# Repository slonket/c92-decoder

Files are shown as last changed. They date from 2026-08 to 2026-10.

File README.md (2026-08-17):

# c92-decoder

### An MM1/MM2/Lenz decoder for classic Märklin locomotives and the pre-mfx digital systems.

The c92 decoder was spawned out of a passion for the classic (pre-mfx) Märklin digital systems. The controllers of this era operated with three different protocols:
- MM1 (6020, 6021, 6022, 6023)
- MM2 (6021)
- Lenz (6027, 6029)

However, no single decoder from this era can operate on all three protocols, nor with all of their capabilities. Furthermore, there is a matrix of incompatibility between different controllers and combinations of decoders using MM1 and MM2. The c92 decoder is a superset of all decoder capabilities and their respective protocols; a universal classic decoder.

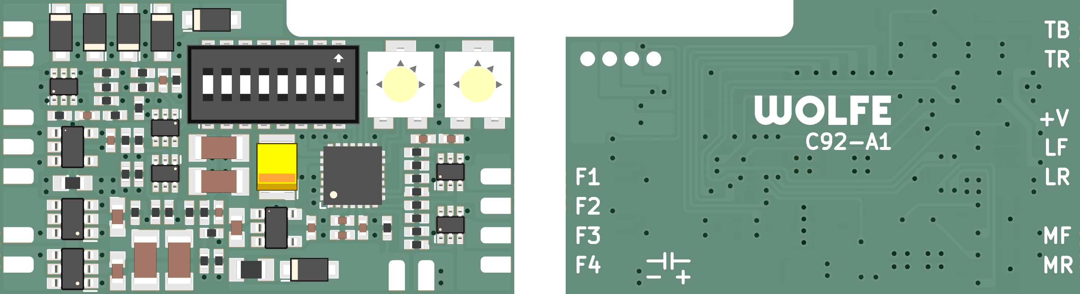
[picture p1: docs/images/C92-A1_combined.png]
c92 decoder back view.


### Cloning

This project uses [`slonket-footprints`](https://github.com/slonket/slonket-footprints) as a submodule for all PCB designs. All KiCAD projects within this repository are configured to use the submodule libraries with local paths. Run the following to clone the repository with its submodule:
```
git clone --recurse-submodules https://github.com/slonket/c92-decoder.git
```

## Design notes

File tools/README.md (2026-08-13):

# c92-decoder - tools

### discrete_hbridge

A development board for the discrete H-bridge design used in the c92 decoder. The H-bridge is unique in being able to operate with low-side FETs always on, while PWM is applied only to the top FETs. This mode is necessary for BEMF measurement referenced to decoder ground.

### hubert_mounts

Mounting hardware for a breadboard to be fastened atop Hubert.

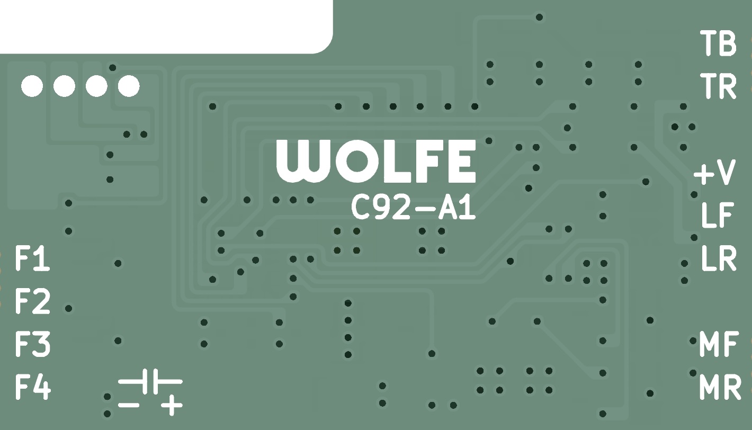
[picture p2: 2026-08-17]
docs/images/C92-A1_back.jpg

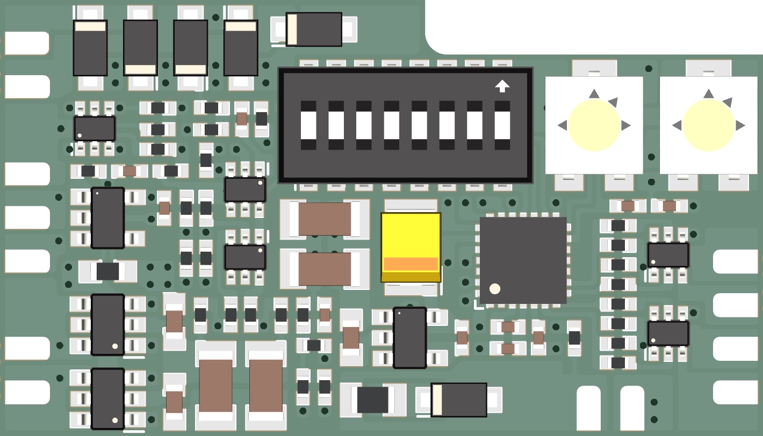
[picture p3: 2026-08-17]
docs/images/C92-A1_front.jpg

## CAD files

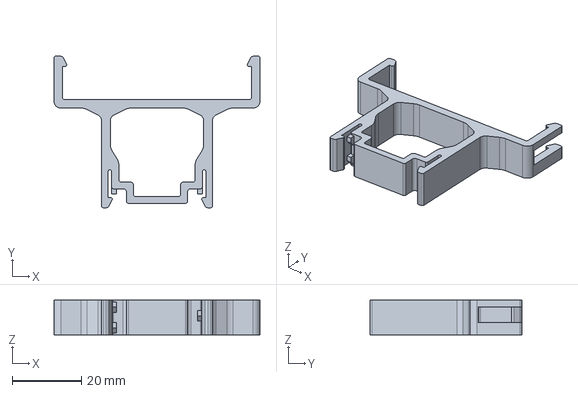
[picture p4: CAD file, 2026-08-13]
tools/hubert_mounts/hubert_mount_B.FCStd
59.5 x 43.8 x 10.0 mm

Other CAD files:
mechanical/C92_bracket.FCStd
tools/hubert_mounts/hubert_mount_A.FCStd

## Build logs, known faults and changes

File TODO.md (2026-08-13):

# c92-decoder

### TODO

- [ ] Write a comprehensive README.md
- [ ] Implement F1-F4 GPIO (held by decoder_state?).
    - Framework DONE - need F3/F4 GPIO setup.
- [ ] Make acceleration potentiometer non-linear and with better range in motor control.
- [ ] Add emergency stop and decoder disable for motor current limit trip.
- [ ] Add analog (DC) operation.
- [ ] Add marklin braking section detection.
- [ ] Store absolute direction in flash between power cycles for MM1.
    - [ ] Store complete state with F1-F4. Use brownout detection?
- [ ] Check MM 81-255 work on other controllers like MS2.
    - [ ] Check the 83-191 address swap on IB-Basic isn't just a bug.
    - [ ] Check all addresses work.
- [x] Connect F4 state to ramp bypass in motor control.
- [x] Add motorola old functions F1-F4.
- [x] Extend MM to use 255 addresses.

### Issues

- [x] The headlight F0 (decoder state) and motor drive direction can go out of sync on motorola old. this is likely due to the use of "change direction" rather than "absolute direction". It is hard to replicate this bug but the change likely requires update_reverse() to provide an absolute direction, and to not use "reverse" on motor_control. This keeps motor_state and motor_control in sync and lets motor_state exclusively handle detection of direction changes.
    - FIXED - Removed reverse in motor control. It is now absolute from decoder state.
- [x] Loco moves briefly in new direction after reverse on MM1.'
    - FIXED - Reversing would only change direction, but not update speed. Fixed by setting motor speed to 0 after update_reverse() for decoder state.

### Revisit

- [ ] Feedback control and PI control system tuning.
- [ ] Speed range minimum value from potentiometer.
    - [ ] Minimum (crawl) speed tuning.
- [ ] Accelation range from potentiometer.
- [ ] Lenz/MM pulse timing tolerances (notably MM between controllers).
- [ ] Initial GPIO states for functions and motor outputs.

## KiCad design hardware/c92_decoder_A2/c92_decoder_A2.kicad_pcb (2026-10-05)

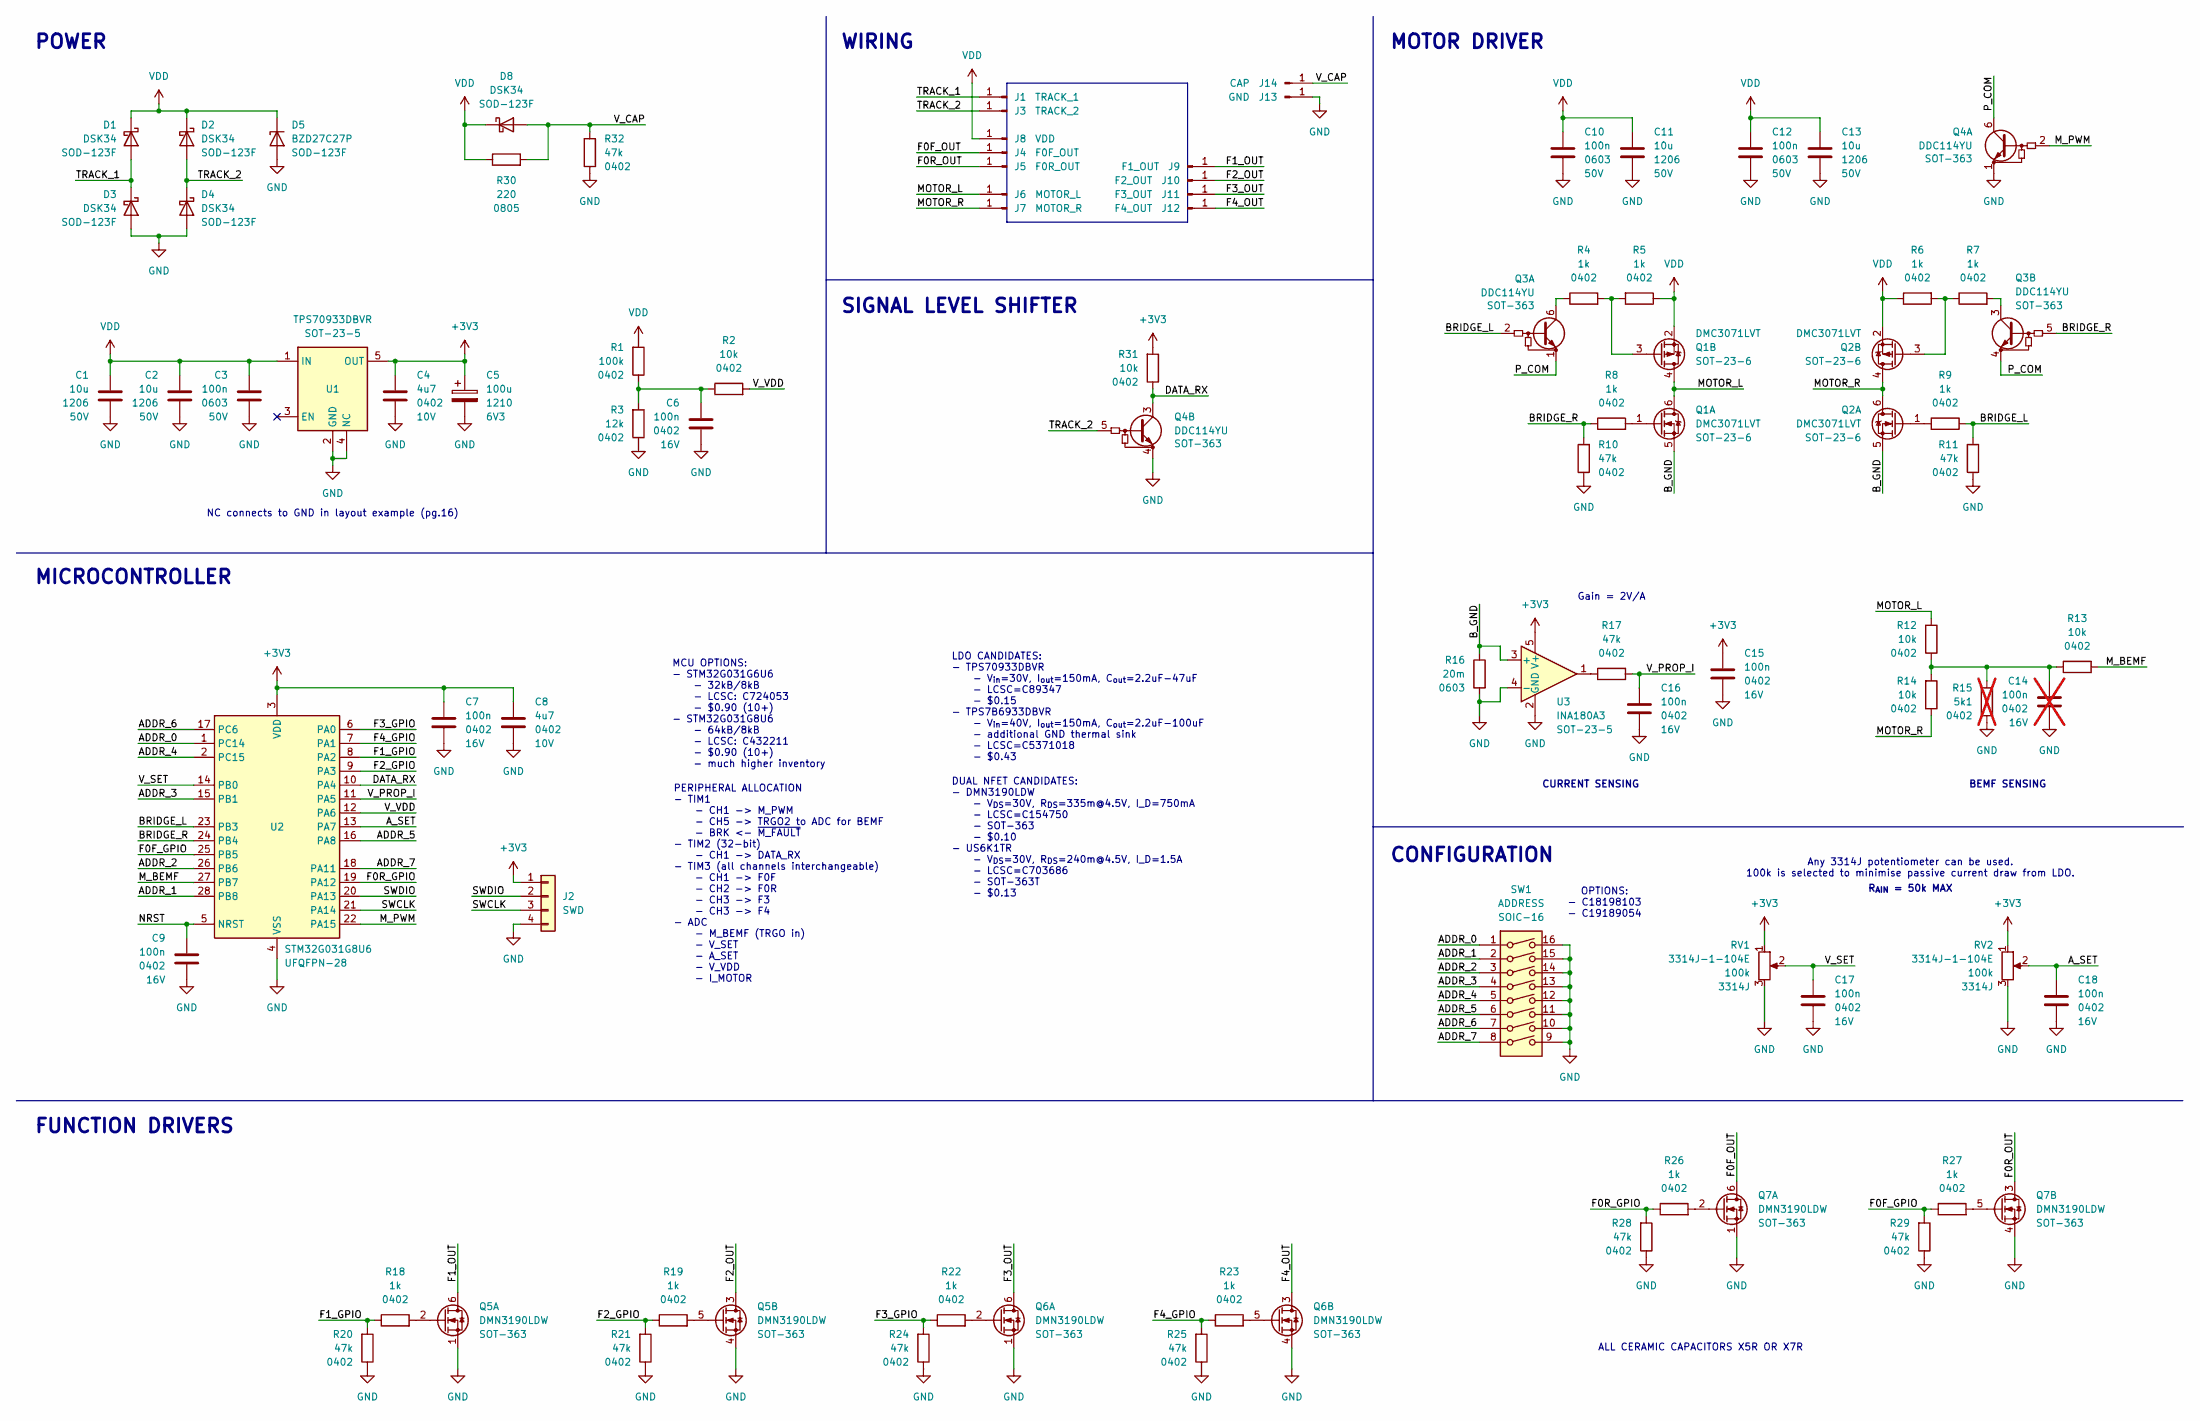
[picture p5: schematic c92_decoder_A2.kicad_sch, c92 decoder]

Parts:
C1, C2, C11, C13: 10u; C_1206; Voltage 50V; LCSC C13585
C3, C10, C12: 100n; C_0603; Voltage 50V; LCSC C14663
C4, C8: 4u7; C_0402; Voltage 10V; LCSC C23733
C5: 100u; CP_1210_CASE_B; Voltage 6V3; LCSC C16133
C6, C7, C9, C15, C16, C17, C18: 100n; C_0402; Voltage 16V; LCSC C1525
C14: 100n; C_0402; Voltage 16V; LCSC C1525; not fitted
D1, D2, D3, D4, D8: DSK34; D_SOD-123F; LCSC C7502709
D5: BZD27C27P; D_SOD-123F; LCSC C5455754
J1: TRACK_1; J_Pad_1mm_2mm
J2: SWD; J_Pad_4_1.5mm
J3: TRACK_2; J_Pad_1mm_2mm
J4: F0F_OUT; J_Pad_1mm_2mm
J5: F0R_OUT; J_Pad_1mm_2mm
J6: MOTOR_L; J_Pad_1mm_2mm
J7: MOTOR_R; J_Pad_1mm_2mm
J8: VDD; J_Pad_1mm_2mm
J9: F1_OUT; J_Pad_1mm_2mm
J10: F2_OUT; J_Pad_1mm_2mm
J11: F3_OUT; J_Pad_1mm_2mm
J12: F4_OUT; J_Pad_1mm_2mm
J13: GND; J_Pad_1mm_2mm
J14: CAP; J_Pad_1mm_2mm
Q1, Q2: DMC3071LVT; U_SOT-23-6; LCSC C17543297
Q3, Q4: DDC114YU; U_SOT-363; LCSC C151389
Q5, Q6, Q7: DMN3190LDW; U_SOT-363; LCSC C154750
R1: 100k; R_0402; LCSC C25741
R2, R12, R13, R14, R31: 10k; R_0402; LCSC C25744
R3: 12k; R_0402; LCSC C25752
R4, R5, R6, R7, R8, R9, R18, R19, R22, R23, R26, R27: 1k; R_0402; LCSC C11702
R10, R11, R17, R20, R21, R24, R25, R28, R29, R32: 47k; R_0402; LCSC C25792
R15: 5k1; R_0402; LCSC C25905; not fitted
R16: 20m; R_0603; LCSC C156372
R30: 220; R_0805; LCSC C17557
RV1, RV2: 3314J-1-104E; RV_BOURNS_3314J; LCSC C51284
SW1: ADDRESS; SW_DIP_8_P1.27; LCSC C18198103
U1: TPS70933DBVR; U_SOT-23-5; LCSC C89347
U2: STM32G031G8U6; U_STM_UFQFPN-28_4x4_P0.5; LCSC C432211
U3: INA180A3; U_SOT-23-5; LCSC C122882

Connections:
+3V3: C4.1, C5.1, C7.1, C8.1, C15.1, J2.1, R31.2, RV1.1, RV2.1, U1.5 (OUT), U2.3 (VDD), U3.5 (V+)
/ADDR_0: SW1.1, U2.1 (PC14)
/ADDR_1: SW1.2, U2.28 (PB8)
/ADDR_2: SW1.3, U2.26 (PB6)
/ADDR_3: SW1.4, U2.15 (PB1)
/ADDR_4: SW1.5, U2.2 (PC15)
/ADDR_5: SW1.6, U2.16 (PA8)
/ADDR_6: SW1.7, U2.17 (PC6)
/ADDR_7: SW1.8, U2.18 (PA11)
/A_SET: C18.1, RV2.2, U2.13 (PA7)
/BRIDGE_L: Q3.2 (B1), R9.1, R11.2, U2.23 (PB3)
/BRIDGE_R: Q3.5 (B2), R8.1, R10.2, U2.24 (PB4)
/B_GND: Q1.5 (S), Q2.5 (S), R16.1, U3.3 (+)
/DATA_RX: Q4.3 (C2), R31.1, U2.10 (PA4)
/F0F_GPIO: R27.1, R29.2, U2.25 (PB5)
/F0F_OUT: J4.1 (Pin_1_1), Q7.6 (D)
/F0R_GPIO: R26.1, R28.2, U2.19 (PA12)
/F0R_OUT: J5.1 (Pin_1_1), Q7.3 (D)
/F1_GPIO: R18.1, R20.2, U2.8 (PA2)
/F1_OUT: J9.1 (Pin_1_1), Q5.6 (D)
/F2_GPIO: R19.1, R21.2, U2.9 (PA3)
/F2_OUT: J10.1 (Pin_1_1), Q5.3 (D)
/F3_GPIO: R22.1, R24.2, U2.6 (PA0)
/F3_OUT: J11.1 (Pin_1_1), Q6.6 (D)
/F4_GPIO: R23.1, R25.2, U2.7 (PA1)
/F4_OUT: J12.1 (Pin_1_1), Q6.3 (D)
/MOTOR_L: J6.1 (Pin_1_1), Q1.4 (D), Q1.6 (D), R12.2
/MOTOR_R: J7.1 (Pin_1_1), Q2.4 (D), Q2.6 (D), R14.1
/M_BEMF: R13.2, U2.27 (PB7)
/M_PWM: Q4.2 (B1), U2.22 (PA15)
/NRST: C9.1, U2.5 (NRST)
/P_COM: Q3.1 (E1), Q3.4 (E2), Q4.6 (C1)
/SWCLK: J2.3, U2.21 (PA14)
/SWDIO: J2.2, U2.20 (PA13)
/TRACK_1: D1.2 (A), D3.1 (K), J1.1 (Pin_1_1)
/TRACK_2: D2.2 (A), D4.1 (K), J3.1 (Pin_1_1), Q4.5 (B2)
/V_CAP: D8.2 (A), J14.1 (Pin_1_1), R30.2, R32.2
/V_PROP_I: C16.1, R17.2, U2.11 (PA5)
/V_SET: C17.1, RV1.2, U2.14 (PB0)
/V_VDD: R2.2, U2.12 (PA6)
GND: C1.2, C2.2, C3.2, C4.2, C5.2, C6.2, C7.2, C8.2, C9.2, C10.2, C11.2, C12.2, C13.2, C14.2, C15.2, C16.2, C17.2, C18.2, D3.2 (A), D4.2 (A), D5.2 (A), J2.4, J13.1 (Pin_1_1), Q4.1 (E1), Q4.4 (E2), Q5.1 (S), Q5.4 (S), Q6.1 (S), Q6.4 (S), Q7.1 (S), Q7.4 (S), R3.1, R10.1, R11.1, R15.1, R16.2, R20.1, R21.1, R24.1, R25.1, R28.1, R29.1, R32.1, RV1.3, RV2.3, SW1.9, SW1.10, SW1.11, SW1.12, SW1.13, SW1.14, SW1.15, SW1.16, U1.2 (GND), U1.4 (NC), U2.4 (VSS), U3.2 (GND), U3.4 (-)
unnamed: C6.1, R1.1, R2.1, R3.2
unnamed: C14.1, R12.1, R13.1, R14.2, R15.2
unnamed: Q1.1 (G), R8.2
unnamed: Q1.3 (G), R4.2, R5.2
unnamed: Q2.1 (G), R9.2
unnamed: Q2.3 (G), R6.2, R7.1
unnamed: Q3.6 (C1), R4.1
unnamed: Q3.3 (C2), R7.2
unnamed: Q5.2 (G), R18.2
unnamed: Q5.5 (G), R19.2
unnamed: Q6.2 (G), R22.2
unnamed: Q6.5 (G), R23.2
unnamed: Q7.2 (G), R26.2
unnamed: Q7.5 (G), R27.2
unnamed: R17.1, U3.1
VDD: C1.1, C2.1, C3.1, C10.1, C11.1, C12.1, C13.1, D1.1 (K), D2.1 (K), D5.1 (K), D8.1 (K), J8.1 (Pin_1_1), Q1.2 (S), Q2.2 (S), R1.2, R5.1, R6.1, R30.1, U1.1 (IN)

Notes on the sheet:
PERIPHERAL ALLOCATION - TIM1 - CH1 -> M_PWM - CH5 -> TRGO2 to ADC for BEMF - BRK <- ~{M_FAULT} - TIM2 (32-bit) - CH1 -> DATA_RX - TIM3 (all channels interchangeable) - CH1 -> F0F - CH2 -> F0R - CH3 -> F3 - CH3 -> F4 - ADC - M_BEMF (TRGO in) - V_SET - A_SET - V_VDD - I_MOTOR
Any 3314J potentiometer can be used. 100k is selected to minimise passive current draw from LDO.
MOTOR DRIVER
ALL CERAMIC CAPACITORS X5R OR X7R
SIGNAL LEVEL SHIFTER
POWER
Gain = 2V/A
DUAL NFET CANDIDATES: - DMN3190LDW - V_{DS}=30V, R_{DS}=335m@4.5V, I_D=750mA - LCSC=C154750 - SOT-363 - $0.10 - US6K1TR - V_{DS}=30V, R_{DS}=240m@4.5V, I_D=1.5A - LCSC=C703686 - SOT-363T - $0.13
OPTIONS: - C18198103 - C19189054
CURRENT SENSING
NC connects to GND in layout example (pg.16)
BEMF SENSING
MCU OPTIONS: - STM32G031G6U6 - 32kB/8kB - LCSC: C724053 - $0.90 (10+) - STM32G031G8U6 - 64kB/8kB - LCSC: C432211 - $0.90 (10+) - much higher inventory
WIRING
CONFIGURATION
FUNCTION DRIVERS
MICROCONTROLLER
LDO CANDIDATES: - TPS70933DBVR - V_{in}=30V, I_{out}=150mA, C_{out}=2.2uF-47uF - LCSC=C89347 - $0.15 - TPS7B6933DBVR - V_{in}=40V, I_{out}=150mA, C_{out}=2.2uF-100uF - additional GND thermal sink - LCSC=C5371018 - $0.43
R_{AIN} = 50k MAX

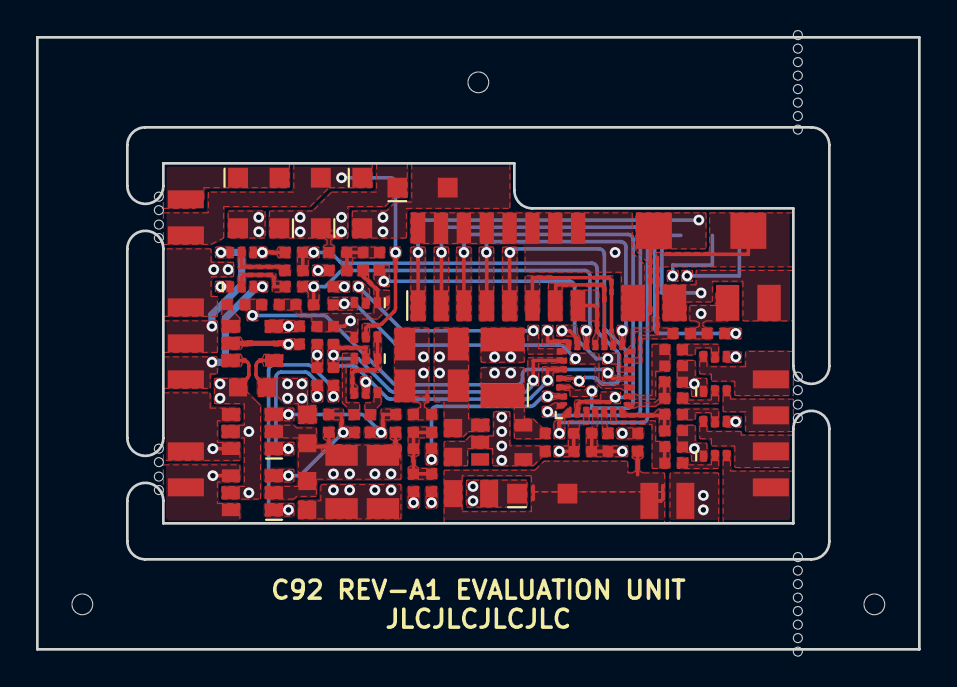
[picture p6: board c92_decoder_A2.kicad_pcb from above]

Board: 4 copper layers, 49.0 x 34.0 mm, 83 parts (1 on the bottom side), 57 nets.

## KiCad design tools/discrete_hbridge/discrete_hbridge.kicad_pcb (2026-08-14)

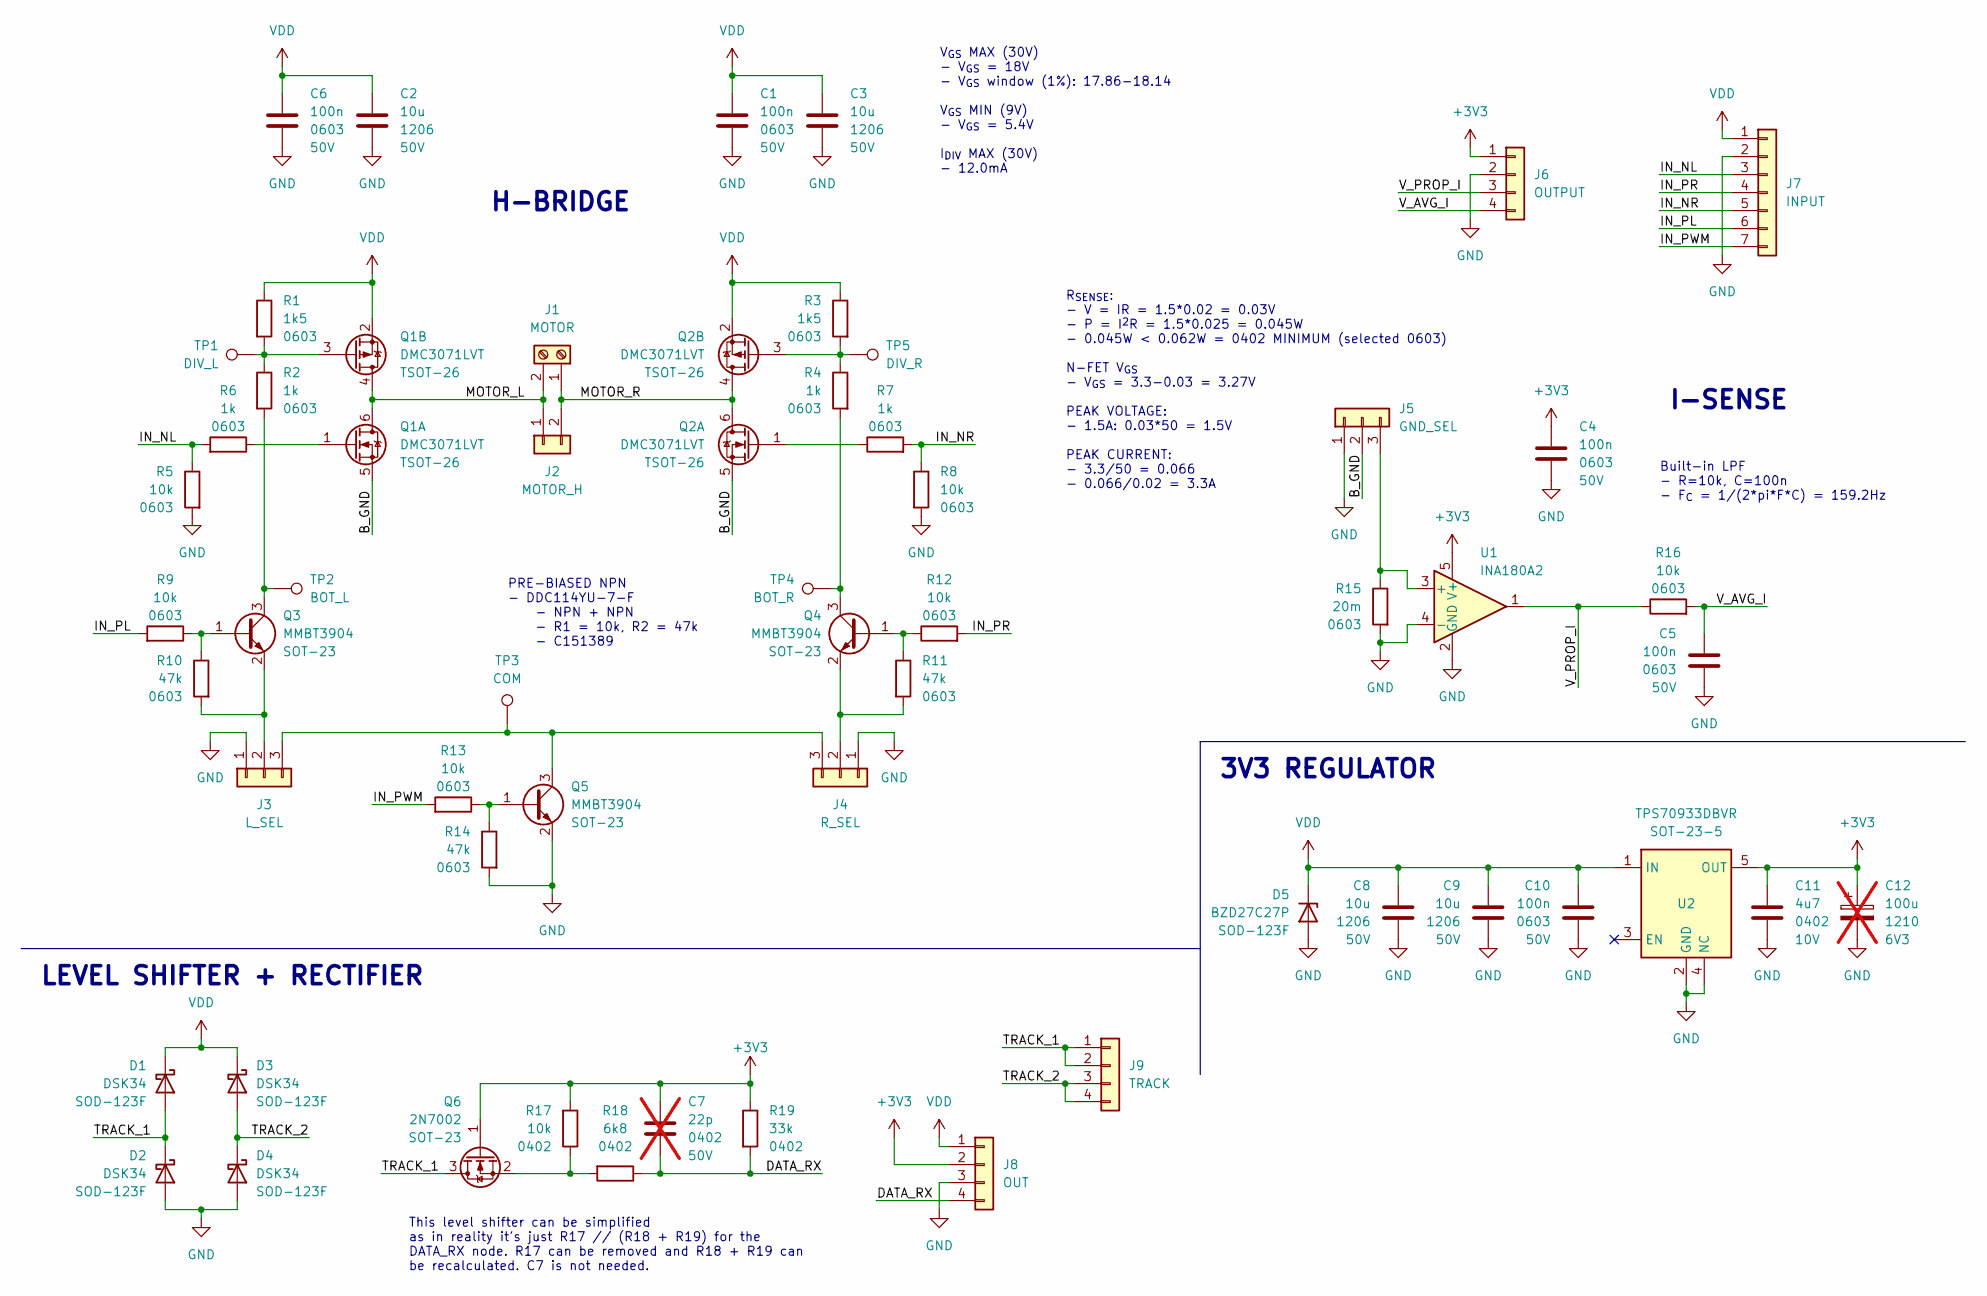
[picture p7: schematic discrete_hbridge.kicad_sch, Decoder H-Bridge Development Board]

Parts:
C1, C4, C5, C6: 100n; C_0603_1608Metric; Voltage 50V; LCSC C14663
C2, C3: 10u; C_1206_3216Metric; Voltage 50V; LCSC C13585
C7: 22p; C_0402; Voltage 50V; LCSC C1653; not fitted
C8, C9: 10u; C_1206; Voltage 50V; LCSC C13585
C10: 100n; C_0603; Voltage 50V; LCSC C14663
C11: 4u7; C_0402; Voltage 10V; LCSC C23733
C12: 100u; CP_1210_CASE_B; Voltage 6V3; LCSC C16133; not fitted
D1, D2, D3, D4: DSK34; D_SOD-123F; LCSC C7502709
D5: BZD27C27P; D_SOD-123F; LCSC C5455754
J1: MOTOR; TerminalBlock_MaiXu_MX126-5.0-02P_1x02_P5.00mm
J2: MOTOR_H; PinHeader_1x02_P2.54mm_Vertical
J3: L_SEL; PinHeader_1x03_P2.54mm_Vertical
J4: R_SEL; PinHeader_1x03_P2.54mm_Vertical
J5: GND_SEL; PinHeader_1x03_P2.54mm_Vertical
J6: OUTPUT; PinHeader_1x04_P2.54mm_Vertical
J7: INPUT; PinHeader_1x07_P2.54mm_Vertical
J8: OUT; PinHeader_1x04_P2.54mm_Vertical
J9: TRACK; PinHeader_1x04_P2.54mm_Vertical
Q1, Q2: DMC3071LVT; TSOT-23-6; LCSC C17543297
Q3, Q4, Q5: MMBT3904; SOT-23; LCSC C7420353
Q6: 2N7002; U_SOT-23; LCSC C8545
R1, R3: 1k5; R_0603_1608Metric; LCSC C22843
R2, R4, R6, R7: 1k; R_0603_1608Metric; LCSC C21190
R5, R8, R9, R12, R13, R16: 10k; R_0603_1608Metric; LCSC C25804
R10, R11, R14: 47k; R_0603_1608Metric; LCSC C25819
R15: 20m; R_0603_1608Metric; LCSC C156372
R17: 10k; R_0402; LCSC C25744
R18: 6k8; R_0402; LCSC C25917
R19: 33k; R_0402; LCSC C25779
TP1: DIV_L; TP_Loop
TP2: BOT_L; TP_Loop
TP3: COM; TP_Loop
TP4: BOT_R; TP_Loop
TP5: DIV_R; TP_Loop
U1: INA180A2; SOT-23-5; LCSC C192764
U2: TPS70933DBVR; U_SOT-23-5; LCSC C89347

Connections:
+3V3: C4.1, C7.1, C11.1, C12.1, J6.1, J8.2, Q6.1 (G), R17.2, R19.1, U1.5 (V+), U2.5 (OUT)
/B_GND: J5.2, Q1.5 (S), Q2.5 (S)
/DATA_RX: C7.2, J8.4, R18.1, R19.2
/IN_NL: J7.3, R5.1, R6.2
/IN_NR: J7.5, R7.2, R8.1
/IN_PL: J7.6, R9.2
/IN_PR: J7.4, R12.2
/IN_PWM: J7.7, R13.2
/MOTOR_L: J1.2, J2.1, Q1.4 (D), Q1.6 (D)
/MOTOR_R: J1.1, J2.2, Q2.4 (D), Q2.6 (D)
/TRACK_1: D1.2 (A), D2.1 (K), J9.1, J9.2, Q6.3 (D)
/TRACK_2: D3.2 (A), D4.1 (K), J9.3, J9.4
/V_AVG_I: C5.1, J6.4, R16.2
/V_PROP_I: J6.3, R16.1, U1.1
GND: C1.2, C2.2, C3.2, C4.2, C5.2, C6.2, C8.2, C9.2, C10.2, C11.2, C12.2, D2.2 (A), D4.2 (A), D5.2 (A), J3.1, J4.1, J5.1, J6.2, J7.2, J8.3, Q5.2 (E), R5.2, R8.2, R14.2, R15.2, U1.2 (GND), U1.4 (-), U2.2 (GND), U2.4 (NC)
unnamed: J3.2, Q3.2 (E), R10.2
unnamed: J3.3, J4.3, Q5.3 (C), TP3.1 (1_1)
unnamed: J4.2, Q4.2 (E), R11.2
unnamed: J5.3, R15.1, U1.3 (+)
unnamed: Q1.1 (G), R6.1
unnamed: Q1.3 (G), R1.2, R2.1, TP1.1 (1_1)
unnamed: Q2.1 (G), R7.1
unnamed: Q2.3 (G), R3.2, R4.1, TP5.1 (1_1)
unnamed: Q3.1 (B), R9.1, R10.1
unnamed: Q3.3 (C), R2.2, TP2.1 (1_1)
unnamed: Q4.1 (B), R11.1, R12.1
unnamed: Q4.3 (C), R4.2, TP4.1 (1_1)
unnamed: Q5.1 (B), R13.1, R14.1
unnamed: Q6.2 (S), R17.1, R18.2
VDD: C1.1, C2.1, C3.1, C6.1, C8.1, C9.1, C10.1, D1.1 (K), D3.1 (K), D5.1 (K), J7.1, J8.1, Q1.2 (S), Q2.2 (S), R1.1, R3.1, U2.1 (IN)

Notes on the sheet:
H-BRIDGE
I-SENSE
3V3 REGULATOR
V_{GS} MAX (30V) - V_{GS} = 18V - V_{GS} window (1%): 17.86-18.14 V_{GS} MIN (9V) - V_{GS} = 5.4V I_{DIV} MAX (30V) - 12.0mA
PRE-BIASED NPN - DDC114YU-7-F - NPN + NPN - R1 = 10k, R2 = 47k - C151389
This level shifter can be simplified as in reality it's just R17 // (R18 + R19) for the DATA_RX node. R17 can be removed and R18 + R19 can be recalculated. C7 is not needed.
Built-in LPF - R=10k, C=100n - F_{C} = 1/(2*pi*F*C) = 159.2Hz
LEVEL SHIFTER + RECTIFIER
R_{SENSE}: - V = IR = 1.5*0.02 = 0.03V - P = I^{2}R = 1.5*0.025 = 0.045W - 0.045W < 0.062W = 0402 MINIMUM (selected 0603) N-FET V_{GS} - V_{GS} = 3.3-0.03 = 3.27V PEAK VOLTAGE: - 1.5A: 0.03*50 = 1.5V PEAK CURRENT: - 3.3/50 = 0.066 - 0.066/0.02 = 3.3A

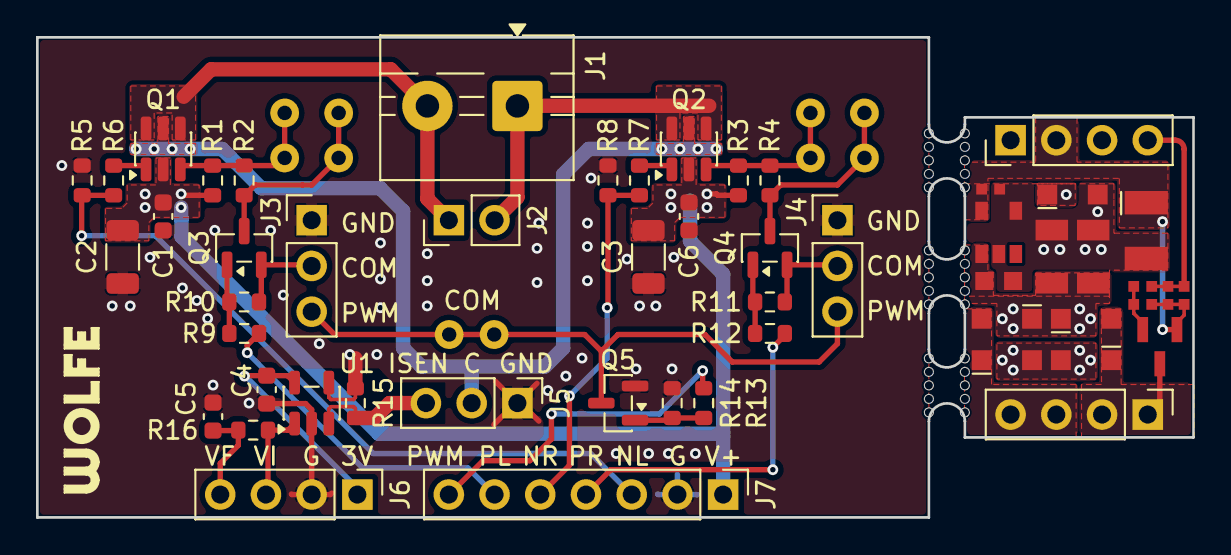
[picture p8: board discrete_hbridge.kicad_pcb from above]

Board: 2 copper layers, 64.2 x 26.7 mm, 58 parts (0 on the bottom side), 30 nets.

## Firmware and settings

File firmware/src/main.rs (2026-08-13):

#![no_std]
#![no_main]

// CORE EMBEDDED INCLUDES
use cortex_m as _;
use cortex_m_rt as rt;
use defmt_rtt as _;
use panic_probe as _;
use stm32g0xx_hal::{self as hal, pac};

// EMBEDDED INCLUDES
use cortex_m::{
    peripheral::NVIC
};
use hal::{
    prelude::*,
    rcc::{Config, Prescaler, PllConfig},
    timer::{pins::TimerPin},
};
use pac::{interrupt, Interrupt};
use rt::{entry};

// OTHER INCLUDES
use core::{
    cell::UnsafeCell,
    mem::MaybeUninit,
};
use defmt::{info, warn};
use mm_decoder::*;
use lenz_decoder::*;

// PROJECT MODULES
mod motor_control;
mod ring_buffer;
mod decoder_state;

use decoder_state::DecoderState;
use ring_buffer::{RingBuffer, RingProducer};
use motor_control::MotorControl;

// MOTOR CONSTANTS
const F_CLK: u32 = 64_000_000;
const F_PWM: u32 = 25_000;
const F_PID: u32 = 100;

const N_DEADTIME: usize = 24;
const N_CYCLES: usize = ((F_PWM/F_PID) as usize) - N_DEADTIME;

const T_PWM: u32 = (F_CLK/F_PWM) - 1;
const T_PWM_LONG: u32 = (F_CLK/F_PWM) * ((N_DEADTIME + 1) as u32) - 1;
const T_ADC: u32 = T_PWM_LONG - ((F_CLK/1_000_000)*10); //10us before end of deadtime

// OTHER CONSTANTS
const N_PULSE_BUF: usize = 64;
const I_TRIP: u32 = 1240; // approx 1V = 1A

const ADDRESS: u8 = 10;

// TYPES
// ADC BUFFER (named u16 array)
#[repr(C)] // this ensures entries are aligned as in C - not rearranged or padded.
struct AdcBuf {
    bemf: u16,
    v_acc: u16,
    v_max: u16,
    i_motor: u16,
}

impl AdcBuf {
    const LEN: usize = 4;
}

// READ-ONLY STATICS - these will live in .rodata (flash only)
static TIM2_ARR_BUF: [u32; N_CYCLES] = {
      let mut buf: [u32; N_CYCLES] = [T_PWM; N_CYCLES];
      buf[N_CYCLES - 1] = T_PWM_LONG;
      buf
};

// READ-WRITE STATICS
#[repr(transparent)]
struct SyncCell<T>(UnsafeCell<T>);
unsafe impl<T> Sync for SyncCell<T> {}

#[unsafe(link_section = ".uninit")] // unloaded RAM section
static ADC_BUF: SyncCell<MaybeUninit<AdcBuf>> = SyncCell(UnsafeCell::new(MaybeUninit::uninit()));
#[unsafe(link_section = ".uninit")] // unloaded RAM section
static PULSE_BUF: SyncCell<MaybeUninit<RingBuffer<u16, N_PULSE_BUF>>> = SyncCell(UnsafeCell::new(MaybeUninit::uninit()));

static PULSE_PROD: SyncCell<Option<RingProducer<'static, u16, N_PULSE_BUF>>> = SyncCell(UnsafeCell::new(None));
static MOTOR_CONTROL: SyncCell<MotorControl> = SyncCell(UnsafeCell::new(MotorControl::new()));



#[entry]
fn main() -> ! {

    // track protocol decoding state machines
    static mut LENZ_MACHINE: LenzMachine = LenzMachine::new();
    static mut MM_LOCO_MACHINE: MmLocoMachine = MmLocoMachine::new();
    static mut MM_ACC_MACHINE: MmAccMachine = MmAccMachine::new();

    // decoder state machine and edge detector
    static mut DECODER_STATE: DecoderState = DecoderState::new();

    // print version at startup
    let version = env!("CARGO_PKG_VERSION");
    info!("C92 FIRMWARE VER-{}", version);

    // peripheral handles
    let dp = pac::Peripherals::take().unwrap();
    let cp = cortex_m::Peripherals::take().unwrap();

    // clock configuration
    let mut rcc = dp.RCC.freeze(Config::pll()
        .pll_cfg(PllConfig::with_hsi(1, 8, 2)) // core clock 64MHz (16MHz HSI x8/2)
        .ahb_psc(Prescaler::NotDivided) // AHB = 64MHz
        .apb_psc(Prescaler::NotDivided) // APB = 64MHz
    );

    // gpio configuration
    let gpioa = dp.GPIOA.split(&mut rcc);
    let gpiob = dp.GPIOB.split(&mut rcc);

    // motor outputs
    let mut motor_fw = gpioa.pa2.into_push_pull_output();
    let mut motor_rv = gpioa.pa3.into_push_pull_output();
    motor_fw.set_low().ok(); // set both low to 100% prevent shoot-through
    motor_rv.set_low().ok();

    // function outputs
    let mut f0_fw = gpiob.pb6.into_open_drain_output();
    let mut f0_rv = gpiob.pb7.into_open_drain_output();
    let mut f1 = gpioa.pa11.into_push_pull_output();
    let mut f2 = gpioa.pa12.into_push_pull_output();
    f0_fw.set_high().ok(); // TEMP only while using open-drain outputs
    f0_rv.set_high().ok();

    // peripheral clock enable
    unsafe {
        let rcc_raw = &*pac::RCC::ptr();
        rcc_raw.ahbenr.modify(|_, w|
            w.dmaen().set_bit() // DMA
        );
        rcc_raw.apbenr1.modify(|_, w|
            w.tim2en().set_bit() // TIM2
        );
        rcc_raw.apbenr2.modify(|_, w|
            w.tim14en().set_bit() // TIM14
            .adcen().set_bit() // ADC
        );
    }

    // DMA setup
    unsafe {
        let dma = &*pac::DMA::ptr();
        let dmamux = &*pac::DMAMUX::ptr();
        let tim2 = &*pac::TIM2::ptr();
        let adc = &*pac::ADC::ptr();

        // DMA channel 1 for TIM2 ARR buffer
        dmamux.c0cr.write(|w| w.dmareq_id().bits(31)); // see Page 298 - Table 55 (31 = TIM2_UP)
        dma.ch1.par.write(|w| w.bits(&tim2.arr as *const _ as u32));
        dma.ch1.mar.write(|w| w.bits(TIM2_ARR_BUF.as_ptr() as u32));
        dma.ch1.ndtr.write(|w| w.bits(TIM2_ARR_BUF.len() as u32));
        dma.ch1.cr.write(|w|
            w.dir().set_bit() // memory to peripheral
            .minc().set_bit() // memory increment
            .pinc().clear_bit() // peripheral address fixed
            .psize().bits(0b10) // 32-bit peripheral
            .msize().bits(0b10) // 32-bit memory
            .circ().set_bit() // circular mode
            .en().set_bit() // enable channel
        );

        // DMA channel 2 for ADC result buffer
        dmamux.c1cr.write(|w| w.dmareq_id().bits(5)); // see Page 298 - Table 55 (5 = ADC)
        dma.ch2.par.write(|w| w.bits(&adc.dr as *const _ as u32));
        dma.ch2.mar.write(|w| w.bits(ADC_BUF.0.get() as u32));
        dma.ch2.ndtr.write(|w| w.bits(AdcBuf::LEN as u32));
        dma.ch2.cr.write(|w|
            w.dir().clear_bit() // peripheral to memory
            .minc().set_bit() // memory increment
            .pinc().clear_bit() // peripheral address fixed
            .psize().bits(0b01) // 16-bit peripheral
            .msize().bits(0b01) // 16-bit memory
            .circ().set_bit() // circular mode
            .tcie().set_bit() // transfer complete interrupt enable
            .en().set_bit() // enable channel
        );
    }

    // ADC setup
    unsafe {
        let adc = &*pac::ADC::ptr();

        // ADC startup procedure
        adc.cfgr2.write(|w| w.ckmode().bits(0b01)); // clock PCLK/2 = 32MHz (must be set before ADC enable)
        adc.cr.write(|w| w.advregen().set_bit()); // enable voltage regulator and wait for stabilisation (20us)
        cortex_m::asm::delay(64 * 20); // 20us delay at 64MHz - see t_ADCVREG_STUP in datasheet
        adc.cr.modify(|_, w| w.adcal().set_bit()); // start calibration (ADC must be disabled)
        while adc.cr.read().adcal().bit_is_set() {} // wait for cal complete
        adc.isr.write(|w| w.adrdy().set_bit()); // clear ADC ready
        adc.cr.modify(|_, w| w.aden().set_bit()); // enable ADC
        while adc.isr.read().adrdy().bit_is_clear() {} // wait for ADC ready
    
        // configure for trigger on TIM1_TRGO2, rising edge, DMA circular, 12-bit
        adc.cfgr1.write(|w|
            w.extsel().bits(0b010) // TRG0 = TIM2_TRGO
            .exten().bits(0b01) // rising edge trigger
            .res().bits(0b00) // 12-bit resolution
            .dmacfg().set_bit() // DMA circular mode
            .dmaen().set_bit() // DMA enable
            .chselrmod().set_bit() // sequenced channel selection (SQ1..SQ8)
        );
        while adc.isr.read().ccrdy().bit_is_clear() {} // wait for channel config ready
        adc.isr.write(|w| w.ccrdy().set_bit()); // clear ready flag
    
        // configure conversion sequence
        adc.chselr_1().write(|w|
            w.sq1().bits(5)     // motor BEMF (PA5)
            .sq2().bits(8)      // acceleration (PA8)
            .sq3().bits(1)      // maximum speed (PA1)
            .sq4().bits(7)      // motor current (PA7)
            .sq5().bits(0b1111) // 1111 = no channel and EOS
        );
        while adc.isr.read().ccrdy().bit_is_clear() {} // wait for channel config ready
        adc.isr.write(|w| w.ccrdy().set_bit()); // clear ready flag
    
        // set sampling time to 79.5 ADC clock cycles => ~2.5uS
        // TODO: Check the sampling time vs. input impedance in datasheet
        adc.smpr.write(|w| w.smp1().bits(0b101));
    
        // start (wait for TRGO2 trigger)
        adc.cr.modify(|_, w| w.adstart().set_bit());
    }

    // PA0 setup (TIM2_CH1 output)
    let motor_pwm = gpioa.pa0;
    TimerPin::<pac::TIM2>::setup(&motor_pwm);

    // TIM2 setup (motor control PA0)
    unsafe {
        let tim2 = &*pac::TIM2::ptr();

        // general timer config
        tim2.arr.write(|w| w.bits(T_PWM)); // set PWM frequency (25kHz)
        tim2.cr1.write(|w|
            w.arpe().set_bit() // preload ARR (prevent glitches with DMA reload)
            .urs().set_bit() // update event only at overflow
        );
        tim2.cr2.write(|w| w.mms().bits(0b101)); // OC2REF (pulse) on TRGO for ADC. See MMS in TIM2_CR2.
        tim2.dier.write(|w| w.ude().set_bit()); // update DMA request enable

        // channel configuration (CH1/CH2)
        tim2.ccmr1_output().write(|w|
            w.oc1m().bits(0b0110) // CH1 PWM mode 1 (low on match)
            .oc1pe().set_bit() // CCR1 preload enable
            .oc2m().bits(0b0111) // CH5 PWM mode 2 (high on match)
            .oc2pe().set_bit() // not strictly necessary as this is loaded once only
        );
        tim2.ccr1.write(|w| w.bits(0)); // CH1 PWM duty cycle is 0 from start - modified by motor control machine
        tim2.ccr2.write(|w| w.bits(T_ADC)); // CH2 ADC read trigger
        tim2.ccer.write(|w|
            w.cc1e().set_bit() // output CH1 (PA0)
        );

        // final counter enable - this enables the whole motor drive sequence with BEMF
        tim2.cr1.modify(|_, w| w.cen().set_bit()); // enable the counter
    }

    // PA4 setup (TIM14_CH1 input)
    let data_input = gpioa.pa4;
    TimerPin::<pac::TIM14>::setup(&data_input);

    // TIM14 setup (track data capture PA4)
    unsafe {
        let tim14 = &*pac::TIM14::ptr();

        tim14.dier.write(|w| w.cc1ie().set_bit()); // enable CC1 interrupt
        tim14.ccmr1_input().write(|w|
            w.ic1f().bits(0b0010) // 0011 N=8, 0010 N=4
            .cc1s().bits(0b01) // CC1 input capture
        );
        tim14.ccer.write(|w|
            w.cc1np().set_bit() // CC1NP=1 + CC1P=1 = both edges
            .cc1p().set_bit()
            .cc1e().set_bit() // input capture enabled
        );
        tim14.psc.write(|w| w.bits(63u32)); // 1MHz counter frequency (1us resolution)
        tim14.cr1.write(|w| w.cen().set_bit()); // enable the counter
    }

    // pulse buffer setup
    let pulse_buf = unsafe { &mut *PULSE_BUF.0.get() };
    pulse_buf.write(RingBuffer::new());
    let (pulse_prod, mut pulse_cons) = unsafe { pulse_buf.assume_init_mut() }.split();
    unsafe { *PULSE_PROD.0.get() = Some(pulse_prod); }

    // motor control setup
    let motor_control = unsafe {
        let mc = &mut *MOTOR_CONTROL.0.get();
        let tim2 = &*pac::TIM2::ptr();
        mc.init(motor_fw, motor_rv, tim2);
        mc
    };

    // decoder state setup
    DECODER_STATE.init(f0_fw, f0_rv);

    // set interrupt priorities and enable
    let mut nvic = cp.NVIC;
    unsafe {
        nvic.set_priority(Interrupt::DMA_CHANNEL2_3, 0b11000000); // lowest priority (3)
        nvic.set_priority(Interrupt::TIM14, 0b00000000); // highest priority (0)
        NVIC::unmask(Interrupt::DMA_CHANNEL2_3);
        NVIC::unmask(Interrupt::TIM14);
    }

    loop {

        // check and process pulses - this will skip other loop items beyond the state machines as well
        if let Ok(pulse) = pulse_cons.get() {

            // processing Lenz protocol
            if let Some(packet) = LENZ_MACHINE.advance(pulse) {
                match packet.get_type() {
                    Some(LenzCommand::Speed(s)) if s.address() == ADDRESS => {
                        // update f0
                        DECODER_STATE.update_f0(s.f0());

                        // update direction
                        if DECODER_STATE.update_direction(s.direction()) {
                            motor_control.new_direction(s.direction());
                        }

                        // update speed
                        if let LenzSpeed::Speed(speed) = s.speed() {
                            if DECODER_STATE.update_speed(speed) {
                                motor_control.new_speed(speed);
                            }
                        }
                    }
                    Some(LenzCommand::Function(f)) if f.address() == ADDRESS => {
                        let states = f.states();
                        f1.set_state(states[0].into()).unwrap();
                        f2.set_state(states[1].into()).unwrap();
                        // f3.set_state(states[2].into()).unwrap();
                        // f4.set_state(states[3].into()).unwrap();
                        motor_control.ramp_bypass(states[3]);
                    }
                    _ => {}
                }
            }

            // processing MM loco protocol
            if let Some(packet) = MM_LOCO_MACHINE.advance(pulse) {

                // ignore packets for foreign addresses
                if packet.ext_address() == ADDRESS {

                    // update f0 - present in every packet
                    DECODER_STATE.update_f0(packet.f0());

                    // update command
                    match packet.command() {
                        MmLocoCommand::OldSpeed(MmSpeed::Speed(speed)) => {
                            if DECODER_STATE.update_speed(speed) {
                                motor_control.new_speed(speed);
                            }
                        }
                        MmLocoCommand::OldSpeed(MmSpeed::Reverse) => {
                            if let Some(direction) = DECODER_STATE.update_reverse() {
                                motor_control.new_direction(direction);
                                // changing direction is independent of speed at the packet level, thus
                                // the speed needs to also be set to 0 to prevent "restarting" in the
                                // new direction.
                                motor_control.new_speed(0);
                            }
                        }
                        MmLocoCommand::NewSpeed { speed: MmSpeed::Speed(speed), direction } => {
                            if DECODER_STATE.update_direction(direction) {
                                motor_control.new_direction(direction);
                            }
                            if DECODER_STATE.update_speed(speed) {
                                motor_control.new_speed(speed);
                            }
                        }
                        MmLocoCommand::Function { speed: MmSpeed::Speed(speed), function, state } => {
                            if DECODER_STATE.update_speed(speed) {
                                motor_control.new_speed(speed);
                            }

                            // set the corresponding function - only one per function packet
                            match function {
                                1 => f1.set_state(state.into()).unwrap(),
                                2 => f2.set_state(state.into()).unwrap(),
                                3 => {} // f3.set_state(state.into()).unwrap(),
                                4 => {
                                    // f4.set_state(state.into()).unwrap();
                                    motor_control.ramp_bypass(state);
                                }
                                _ => {}
                            }
                        }
                        _ => {} // MM2 reverse commands are ignored - TODO maybe not?
                    }
                }
            }

            // processing MM accessory (old function) protocol
            if let Some(packet) = MM_ACC_MACHINE.advance(pulse) {
                if let MmAccCommand::Func(f) = packet.get_type() {

                    // ignore packets for foreign addresses
                    if f.ext_address() == ADDRESS {

                        // update all functions
                        let states = f.states();
                        f1.set_state(states[0].into()).unwrap();
                        f2.set_state(states[1].into()).unwrap();
                        // f3.set_state(states[2].into()).unwrap();
                        // f4.set_state(states[3].into()).unwrap();
                        motor_control.ramp_bypass(states[3]);
                    }
                }
            }
        }

        // anything else to do in main loop? put it here :)
    }
}

#[interrupt]
fn DMA_CHANNEL2_3() {

    // local statics
    static mut DECIMATOR: u8 = 0;
    static mut ACC_CUM: u16 = 0;
    static mut VMAX_CUM: u16 = 0;

    static mut BEMF_IIR: i32 = 0;

    // global static handles
    let dma = unsafe { &*pac::DMA::ptr() };
    let dma_buf = unsafe { (&*ADC_BUF.0.get()).assume_init_ref() };
    let motor_control = unsafe { &mut *MOTOR_CONTROL.0.get() };

    // clear interrupt flag
    dma.ifcr.write(|w| w.ctcif2().set_bit());

    // BEMF IIR filter - set to 1/2 (shift 1)
    // this is necessary with the marklin 5-pole DCM motor. Compared to finer DC motors, the mechanical gear drive
    // of models with this motor causes a lot of noise on the BEMF signal. What is being read is the true BEMF value
    // at any given instant, but it causes a lot of instability in the PI controller. Thus, it's software filtered. Note
    // the BEMF dividers also have a hardware RC filter for commutator/general noise.
    *BEMF_IIR += ((dma_buf.bemf as i32) - *BEMF_IIR) >> 1;

    // update the motor machine
    motor_control.tick(*BEMF_IIR as u16);
    
    // updating the config - 8 sample average
    if *DECIMATOR >= 7 {
        // divide both by 8
        let acc = *ACC_CUM >> 3;
        let vmax = *VMAX_CUM >> 3;

        // update machine config variables
        motor_control.new_config(acc, vmax);

        // reset accumulators and decimator - store current values for next 8
        *ACC_CUM = dma_buf.v_acc;
        *VMAX_CUM = dma_buf.v_max;
        *DECIMATOR = 0;
    } else {
        // add values this cycle and store
        *ACC_CUM += dma_buf.v_acc;
        *VMAX_CUM += dma_buf.v_max;
        *DECIMATOR += 1;
    }
}

#[interrupt]
fn TIM14() {

    static mut LAST_CCR1: u16 = 0;

    let tim14 = unsafe { &*pac::TIM14::ptr() };
    let gpioa = unsafe { &*pac::GPIOA::ptr() };
    let prod = unsafe { &mut *PULSE_PROD.0.get() }.as_mut().unwrap();

    // read the new edge value (also clears interrupt flag) and status register
    let ccr1 = tim14.ccr1.read().bits() as u16;
    let sr = tim14.sr.read();

    // check for overcapture - 0 if OVC, pulse 
    let raw_pulse = if sr.cc1of().bit_is_set() {
        tim14.sr.write(|w| unsafe { w.bits(!0) }.cc1of().clear_bit());
        warn!("Overcapture occured!");
        0
    } else {
        ccr1.wrapping_sub(*LAST_CCR1)
    };

    // applying asymmetry correction due to level shifter
    const ASYM_COMP_US: u16 = 3;
    let pulse = if raw_pulse == 0 {
        0
    } else if gpioa.idr.read().idr4().bit_is_set() {
        raw_pulse.saturating_sub(ASYM_COMP_US)
    } else {
        raw_pulse.saturating_add(ASYM_COMP_US)
    };

    // push to buffer, reset if overflow occurs
    if prod.put(pulse).is_err() {
        prod.reset();
        let _ = prod.put(0); // put sentinel "reset" for state machines
        warn!("Pulse buffer overflow!");
    }

    // store the new edge for next ISR
    *LAST_CCR1 = ccr1;
}

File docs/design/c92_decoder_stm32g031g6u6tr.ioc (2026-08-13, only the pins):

Mcu.UserName=STM32G031G6Ux
PA0.GPIO_Label=F4
PA0.Signal=GPIO_Output
PA1.GPIO_Label=F3
PA1.Signal=GPIO_Output
PA13.Signal=SYS_SWDIO
PA14-BOOT0.Signal=SYS_SWCLK
PA15.GPIO_Label=M_PWM
PA15.Signal=S_TIM2_CH1_ETR
PA2.GPIO_Label=F2
PA2.Signal=GPIO_Output
PA3.GPIO_Label=F1
PA3.Signal=GPIO_Output
PA4.GPIO_Label=DATA_IN
PA4.Signal=S_TIM14_CH1
PA5.GPIO_Label=V_PROP_I
PA5.Signal=ADC1_IN5
PA6.GPIO_Label=V_VDD
PA6.Signal=ADC1_IN6
PA7.GPIO_Label=A_SET
PA7.Signal=ADC1_IN7
PA8.GPIO_Label=ADDR_5
PA8.Signal=GPIO_Input
PB0.GPIO_Label=V_SET
PB0.Signal=ADC1_IN8
PB1.GPIO_Label=F0F
PB1.Signal=GPIO_Output
PB3.GPIO_Label=BRIDGE_L
PB3.Signal=GPIO_Output
PB4.GPIO_Label=BRIDGE_R
PB4.Signal=GPIO_Output
PB5.GPIO_Label=ADDR_4
PB5.Signal=GPIO_Input
PB6.GPIO_Label=ADDR_2
PB6.Signal=GPIO_Input
PB7.GPIO_Label=M_BEMF
PB7.Signal=ADC1_IN11
PB8.GPIO_Label=ADDR_1
PB8.Signal=GPIO_Input
PC6.GPIO_Label=ADDR_6
PC6.Signal=GPIO_Input

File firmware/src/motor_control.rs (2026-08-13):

use stm32g0xx_hal::{
    prelude::OutputPin,
    pac::tim2,
    gpio::{PA2, PA3, Output, PushPull},
};
use core::ptr::write_volatile;

/// MOTOR CONTROLLER
/// There are many factors that can be used to tune this controller, some that are outside of its constants.
/// Here are the internal configurations related directly to the PI controller:
/// - PI_KI - Integrator coefficient.
/// - PI_KP - Proportion coefficient.
/// - I_PRELOAD - Integrator kick-start value for starting from 0. This must be adjusted after KI/KP for smooth start.
/// 
/// The BEMF value is also filtered twice - first in hardware using a divider-RC filter, and then again in software using
/// an IIR filter. Since BEMF is measured against fixed ranges in software (e.g. 3200 maximum), the maximum speed that can
/// be measured and achieved is thus set by the BEMF divider. Currently there is an approximate 1/4 divider with 100nF filter
/// capacitor.
/// 
/// The motor is very noisy at high speed - so much so that it's difficult to get stable measurements, hence the large filter capacitor.
/// Two factors can be adjusted for the BEMF hardware filtering:
/// - N_DEADTIME in main.rs - number of "dead" PWM cycles used for BEMF measurement settling.
/// - C_filter - the capacitor in the divider-RC filter.
/// 
/// A larger filter cap sets a lower cutoff frequency and rejects more noise, however this also extends BEMF settling time.
/// Thus N_DEADTIME must also be suitable. N_DEADTIME should be as short as possible so as not to affect drive strength.
/// 
/// Lastly, there is an IIR filter for BEMF samples. This should also be set to as little as possible - a larger value
/// increases phase delay, which makes the controller laggy. It can cause oscillation if too long. This can be changed
/// in the DMA_CHANNEL2_3 ISR.

// BEMF CONTROL CONSTANTS
const BEMF_OFF: u16 = 20; // BEMF value to consider the loco "stopped" for state-transition
const BEMF_MIN: u16 = 40; // minimum speed value
const BEMF_MAX: u16 = 3760; // maximum speed value (12V BEMF from divider = 3.03V)
const BEMF_LUT: [u16; 14] = { // LUT of BEMF values from speed settings

    // variables
    let base: u64 = 1150; // exponential base (x1000)

    // array for raw exponential curve
    let mut exp_raw = [1_000_000u64; 14];

    // calculate each value
    let mut i = 1;
    while i < 14 {
        // the base is multiplied by 1000 (e.g. 1.15 = 1150)
        // multiply by base then divide by 1000 -> this is an integer version of
        // directly multiplying by what would be the float base (with 3 digit precision)
        exp_raw[i] = (exp_raw[i-1] * base) / 1000;
        i += 1;
    }

    // scale each value from 0 to 65535 (u16 full range)
    let mut lut: [u16; 14] = [0; 14];
    let mut i = 0;
    while i < 14 {
        lut[i] = (((exp_raw[i] - exp_raw[0]) * 65535) / (exp_raw[13] - exp_raw[0])) as u16;
        i += 1;
    }

    lut
};

// PI CONTROLLER CONSTANTS
const PI_KP: i32 = 1024; // proportion co-efficient
const PI_KI: i32 = 64; // integrator co-efficient
const PI_SHIFT: u8 = 10; // fixed-point arithmatic scaling factor (64 fractional values)
const PI_MAX: i32 = 2559; // maximum PWM CCR1 value from PI controller
const PI_MIN: i32 = 0; // minimum PWM CCR1 value from PI controllers
const I_PRELOAD: i32 = 128_000; // kickstart value from stand-still (idle)

// MOTOR CONTROL
enum MotorState {
    Idle,
    Run,
    Brake
}

#[derive(PartialEq, Clone, Copy)]
enum Direction {
    Forward,
    Reverse
}

impl From<bool> for Direction {
    fn from(value: bool) -> Self {
        match value {
            false => Direction::Reverse,
            true => Direction::Forward,
        }
    }
}

pub struct MotorControl {

    // target BEMF calculation variables
    speed: u8,
    bemf_max: u16,
    bemf_target: u16, // target value for BEMF to reach
    bemf_setpoint: u16, // ramped value approaching bemf_target to simulate acceleration
    pot_acc: u16,

    // PI controller variables
    pi_integral: i32,

    // state machine variables
    state: MotorState,
    direction: Direction,
    pending_direction: Direction,
    ramp_bypass: bool,

    // controllable outputs
    motor_fw: Option<PA2<Output<PushPull>>>,
    motor_rv: Option<PA3<Output<PushPull>>>,
    motor_pwm: Option<*mut u32>,
}

impl MotorControl {

    /// Constructor for static initialisation
    pub const fn new() -> Self {
        Self {
            speed: 0,
            bemf_max: 0,
            bemf_target: 0,
            bemf_setpoint: 0,
            pot_acc: 0,
            pi_integral: 0,
            state: MotorState::Idle,
            direction: Direction::Forward,
            pending_direction: Direction::Forward,
            ramp_bypass: false,
            motor_fw: None,
            motor_rv: None,
            motor_pwm: None,
        }
    }

    /// Set the runtime values (pins, CCR1). MUST BE CALLED BEFORE tick()
    pub fn init(&mut self, motor_fw: PA2<Output<PushPull>>, motor_rv: PA3<Output<PushPull>>, tim2: &tim2::RegisterBlock) {
        self.motor_fw = Some(motor_fw);
        self.motor_rv = Some(motor_rv);
        self.motor_pwm = Some(&tim2.ccr1 as *const _ as *mut u32);
    }

    /// Progress the motor state machine and PI controller (if running)]. init() MUST BE CALLED FIRST. This
    /// configures the run-time pins and register which this machine controls.
    pub fn tick(&mut self, bemf: u16) {

        // handles for the motor direction GPIO
        let motor_fw = unsafe { self.motor_fw.as_mut().unwrap_unchecked() };
        let motor_rv = unsafe { self.motor_rv.as_mut().unwrap_unchecked() };
        let motor_pwm = unsafe { self.motor_pwm.unwrap_unchecked() };

        // setpoint ramping - pot_acc (0-4095) controls ramp rate per tick
        // if bypass is on, this is set to the maximum (1 step/tick);
        // TODO revise the ramp step to be non-linear
        let ramp_step = match self.ramp_bypass {
            false => {
                1 + (self.pot_acc / 64) as u16 // 1-64 BEMF units per tick
            }
            true => 64
        };

        // move setpoint towards bemf_target - this is an idiom using saturating operations
        self.bemf_setpoint = self.bemf_target.clamp(
            self.bemf_setpoint.saturating_sub(ramp_step),
            self.bemf_setpoint.saturating_add(ramp_step),
        );
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

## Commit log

2026-08-13 initial repo creation from local work
    [C92_bracket.FCStd, c92_decoder.kicad_pcb, c92_decoder.kicad_sch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]
2026-08-13 Added tools README.md and removed .stl artefacts
    [hubert_mount_A.stl, hubert_mount_B.stl]
2026-08-14 Updated title blocks of PCBA projects
    [c92_decoder.kicad_pcb, c92_decoder.kicad_sch, discrete_hbridge.kicad_pcb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]
2026-08-14 Moved to using slonket-footprints as git submodule
2026-08-14 Updated slonket-footprints
2026-08-14 Switched submodule URL to HTTP (from SSH)
2026-08-29 organised hardware into versioned folder
    [c92_decoder_A1.kicad_pcb, c92_decoder_A1.kicad_sch]
2026-08-31 started B1 hardware
    [c92_decoder_B1.kicad_pcb, c92_decoder_B1.kicad_sch]
2026-10-05 added REV-A2 hardware (BOM change)
    [c92_decoder_A2.kicad_pcb, c92_decoder_A2.kicad_sch]
2026-10-16 new KiCAD structure for multiple variants
